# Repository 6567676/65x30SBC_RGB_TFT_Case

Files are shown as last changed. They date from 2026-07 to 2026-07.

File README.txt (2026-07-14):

项目简介

适配30×65mm sbc的rgb+副屏海景房机箱
android设备通过app与ble蓝牙控制灯效与副屏
7颗ws2812支持三种灯效，通过android设备外录与内录实现频谱拾音灯
st7789 1.47寸 320×172副屏支持显示图片与播放视频
视频最高70s 21fps@rgb565，插帧后可达42fps
机箱两侧设有风扇主动散热

技术实现

基于esp32 s3 n16r8  st7789  ws2812  rtos  android15
双核四缓冲流水线，块匹配运动补偿+加权混色插帧，dma行扫描刷新，flash增量擦除顺序写入
gamma曲线呼吸，脉冲灯效，频谱灯低通滤波，自定义gamma lut(解决ws2812高亮度变化小问题)
nim ble零配对mtu 247，三通道分离指令/数据/回执，状态机分流，视频帧异步落flash，ack回执流控
外录+内录双音源切换，实时FFT频谱分析，7频段dBFS归一化+自动对比度拉伸
MediaCodec解码+自定义裁剪区域，逐帧JPEG压缩，本地存储预览+异步上传

开源协议

CC BY-NC 4.0
Copyright (c) 2026 6567676
You are free to:
  - Share and redistribute in any medium or format
  - Remix, transform, and build upon the material
Under the following terms:
  - NonCommercial only
Full license: https://creativecommons.org/licenses/by-nc/4.0/

其他

此项目仅在瑞莎zero 3w，hyperOS 3完成验证

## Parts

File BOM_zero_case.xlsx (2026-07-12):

No. | Quantity | Comment | Footprint | Manufacturer Part | Manufacturer
1 | 6 | 100nF | C0603 | 0603B104K500NT | FH(风华)
2 | 2 | 1uF | C0805 | 0805B105K500NT | FH(风华)
3 | 1 | FC-05A8P11H20 | FPC-SMD_8P-P0.50_FC05-S08FCT-00 | FC-05A8P11H20 | BXCONN(宝讯)
4 | 7 | WS2812B-V5/W | LED-SMD_4P-L5.0-W5.0-TL-1 | WS2812B-V5/W | worldsemi
5 | 1 | AMS1117-3.3V | SOT-89-3_L4.5-W2.5-P1.50-LS4.2-BR | AMS1117-3.3V | MSKSEMI(美森科)
6 | 1 | 10kΩ | R0603 | FRC0603J472 TS | FOJAN(富捷)
7 | 2 | 5.1kΩ | R0603 | FRC0603J472 TS | FOJAN(富捷)
8 | 1 | 10Ω | R0603 | FRC0603J472 TS | FOJAN(富捷)
9 | 1 | TS-1088-AR02016 | SW-SMD_L3.9-W3.0-P4.45 | TS-1088-AR02016 | XUNPU(讯普)
10 | 1 | 2.4GHz | WIRELM-SMD_ESP32-S3-WROOM-1 | ESP32-S3-WROOM-1-N16R8 | ESPRESSIF(乐鑫)
11 | 1 | TYPE-C 16PIN 2MD(073) | USB-C-SMD_TYPE-C-16PIN-2MD-073 | TYPE-C 16PIN 2MD(073) | SHOU HAN(首韩)
12 | 2 | 1.15cfm | 2510 | 散热风扇
13 | 6 |  | M3*2.5 | 热熔螺母
14 | 4 |  | M3*4 | 尼龙螺丝
15 | 2 |  | M3*6 | 尼龙螺丝
16 | 4 |  | M2.5*8 | 尼龙螺丝
17 | 4 |  | M2.5*14 | 尼龙螺丝
18 | 4 |  | M2.5 | 尼龙螺母
19 | 4 |  | 4*2.7*2 | 隔离柱
20 | 1 | 320*172 262k | 1.47寸 插接8p | ST7789 TFT彩屏
21 | 1 | 84*27*1mm |  | 亚克力板
22 | 1 | 84*28*1mm |  | 亚克力板
23 |  |  |  | 硅橡胶 焊锡

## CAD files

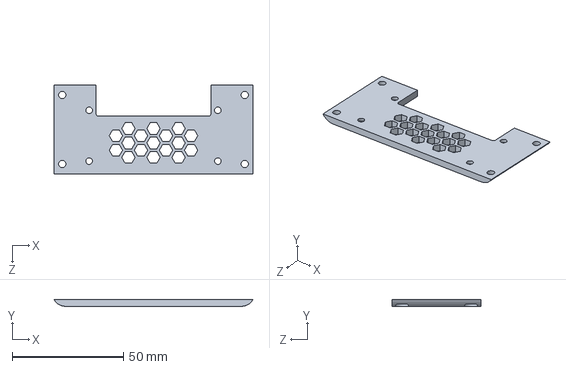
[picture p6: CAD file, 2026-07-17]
zero_case_part/底板.SLDPRT
89.4 x 3.00 x 40.0 mm

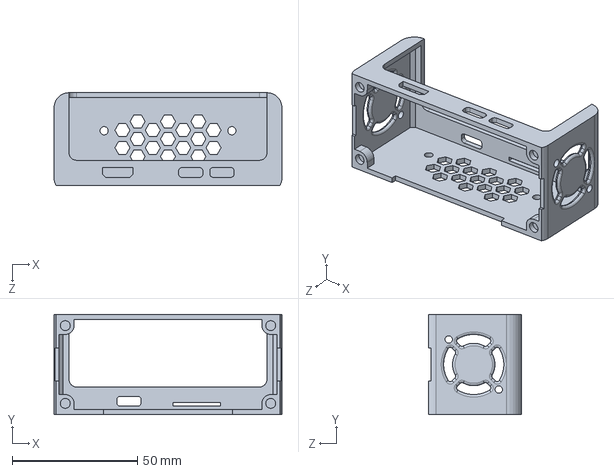
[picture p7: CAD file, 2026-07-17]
zero_case_part/主体.SLDPRT
91.0 x 40.0 x 37.0 mm

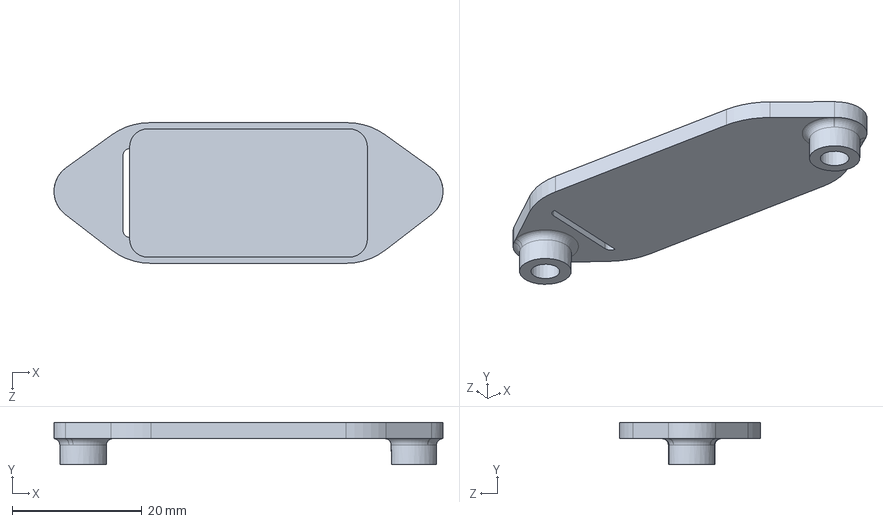
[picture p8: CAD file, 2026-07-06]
zero_case_part/屏幕支架.SLDPRT
60.0 x 6.50 x 21.7 mm

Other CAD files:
zero_case_part/主体.STL
zero_case_part/屏幕支架.STL
zero_case_part/底板.STL

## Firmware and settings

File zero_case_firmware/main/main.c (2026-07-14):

#include <string.h>
#include <stdio.h>
#include <math.h>
#include "freertos/FreeRTOS.h"
#include "freertos/task.h"
#include "freertos/semphr.h"
#include "esp_log.h"
#include "esp_timer.h"
#include "nvs_flash.h"
#include "nvs.h"
#include "driver/spi_master.h"
#include "driver/gpio.h"
#include "esp_flash.h"
#include "esp_heap_caps.h"

#include "nimble/nimble_port.h"
#include "nimble/nimble_port_freertos.h"
#include "host/ble_hs.h"
#include "host/ble_gatt.h"
#include "services/gap/ble_svc_gap.h"
#include "services/gatt/ble_svc_gatt.h"

#include "led_strip.h"
#include "jpeg_decoder.h"

static const char *TAG = "ZERO_BOX";

// ==================== BLE ====================
#define BLE_DEVICE_NAME    "zero box"
#define ZEROBOX_SVC_UUID   0xFF01
#define ZEROBOX_CMD_UUID   0xFF02
#define ZEROBOX_DATA_UUID  0xFF03
#define ZEROBOX_ACK_UUID   0xFF04

// ==================== 硬件 ====================
#define WS2812_GPIO_NUM    38
#define LED_NUM            7
#define LED_MODE_ON        1
#define LED_MODE_BREATH    2
#define LED_MODE_PULSE     3
#define LED_MODE_AUDIO     4

#define IMAGE_W           320
#define IMAGE_H           172
#define IMAGE_SIZE        (IMAGE_W * IMAGE_H * 2)

#define LCD_HOST          SPI2_HOST
#define LCD_SCL           17
#define LCD_SDA           16
#define LCD_CS            18
#define LCD_DC            15
#define LCD_RES           7


// ==================== Flash 存储 ====================
#define MEDIA_FLASH_ADDR    0x320000
#define MEDIA_FLASH_SIZE    (14 * 1024 * 1024)
#define MEDIA_SECTOR_SIZE   8192
#define MEDIA_DATA_START    (MEDIA_FLASH_ADDR + MEDIA_SECTOR_SIZE)

#define IMAGE_MAGIC         0x494D4700
#define VIDEO_MAGIC         0x56494445
#define MAX_VIDEO_FRAMES    1422
#include "freertos/queue.h"
static const uint8_t audio_lut[] = {
     3,  4,  5,  6,  7,  8,  9, 10, 11, 12, 13, 14, 15, 16, 17, 18,
    19, 20, 21, 22, 23, 24, 25, 26, 27, 28, 29, 30, 31, 32, 33, 34,
    35, 36, 37, 38, 39, 40, 41, 42, 43, 44, 45, 46, 47, 48, 49, 50,
    51, 53, 55, 58, 61, 65, 69, 74, 79, 85, 91, 98,105,113,121,130,
   139,148,158,168,178,189,200,211,222,233,244,255
};

// ==================== JPEG 缓冲 ====================
#define JPEG_BUF_SIZE      (96 * 1024)
typedef struct {
    uint8_t *data;
    uint32_t len;
} flash_write_item_t;
static QueueHandle_t flash_queue = NULL;

static uint8_t  jpeg_buf[JPEG_BUF_SIZE] __attribute__((aligned(4)));
static int      jpeg_offset = 0;
static int      jpeg_expected = 0;
static bool     jpeg_receiving = false;

static uint8_t  g_image_data[IMAGE_SIZE] __attribute__((aligned(4)));
static bool     g_image_valid = false;

static uint16_t audio_bands[7] = {0};
static uint8_t  audio_level = 0;
static bool     audio_active = false;
static uint8_t *vbuf[4] = {NULL, NULL, NULL, NULL};

// ==================== LED ====================
static uint8_t led_current_mode = LED_MODE_ON;
static uint8_t prev_mode = 0;
static uint8_t target_r = 255, target_g = 255, target_b = 255;
static uint8_t global_brightness = 255;

static led_strip_handle_t  led_strip;
static spi_device_handle_t  lcd_spi;

// ==================== BLE 状态 ====================
static uint16_t ble_conn_handle = BLE_HS_CONN_HANDLE_NONE;
static uint8_t  ble_addr_type;
static int      ble_img_offset = 0;
static bool     ble_img_receiving = false;
static SemaphoreHandle_t img_save_sem = NULL;
static SemaphoreHandle_t jpeg_decode_sem = NULL;

static uint16_t ack_chr_val_handle = 0;
static bool     ack_subscribed = false;

// ==================== 视频接收状态 ====================
static bool     video_receiving = false;
static int      video_state = 0;
static int      video_total_frames = 0;
static int      video_current_frame = 0;
static int      video_frame_size = 0;
static int      video_frame_offset = 0;
static uint32_t video_frame_sizes[MAX_VIDEO_FRAMES];
static int      video_queued_frames = 0;
static uint32_t video_flash_addr = 0;
static uint32_t video_next_erase = 0;

// ==================== 视频播放状态（从 Flash 加载）====================
static volatile bool     has_stored_video = false;
static int      stored_video_frames = 0;
static uint32_t stored_frame_sizes[MAX_VIDEO_FRAMES];
static uint32_t stored_frame_offsets[MAX_VIDEO_FRAMES];

// 播放控制
static volatile bool     playback_active = false;
static volatile int video_progress_percent = -1;
static bool screen_cleared = false;

// 双核播放
static QueueHandle_t display_queue = NULL;
static QueueHandle_t buf_free_queue = NULL;

#define NVS_CFG_NAMESPACE  "led_cfg"

// ==================== 亮度计算 ====================
static inline uint8_t calc_brightness(uint8_t phase) {
    uint32_t x = (phase < 128) ? phase : (256 - phase);
    return (uint8_t)(5 + (250 * x * (256 - x)) / 16384);
}

// ==================== JPEG 解码 ====================
static esp_err_t decode_jpeg_to_rgb565(const uint8_t *jpg, int jpg_len,
                                        uint8_t *out, int out_size) {
    esp_jpeg_image_cfg_t cfg = {
        .indata = (uint8_t *)jpg,
        .indata_size = jpg_len,
        .outbuf = out,
        .outbuf_size = out_size,
        .out_format = JPEG_IMAGE_FORMAT_RGB565,
        .out_scale = JPEG_IMAGE_SCALE_0,
        .flags = { .swap_color_bytes = 1 },
    };
    esp_jpeg_image_output_t img;
    return esp_jpeg_decode(&cfg, &img);
}

// ==================== BLE ACK 发送 ====================
static void send_ack(uint8_t ack_code) {
    if (!ack_subscribed || ble_conn_handle == BLE_HS_CONN_HANDLE_NONE) return;
    struct os_mbuf *om = ble_hs_mbuf_from_flat(&ack_code, 1);
    if (om) {
        ble_gattc_notify_custom(ble_conn_handle, ack_chr_val_handle, om);
    }
}

static void save_image_to_flash(const uint8_t *data, size_t len) {
    if (len != IMAGE_SIZE) return;
    playback_active = false;
    has_stored_video = false;
    size_t erase_size = MEDIA_SECTOR_SIZE + len;
    erase_size = (erase_size + MEDIA_SECTOR_SIZE - 1) & ~(MEDIA_SECTOR_SIZE - 1);
    esp_flash_erase_region(NULL, MEDIA_FLASH_ADDR, erase_size);
    uint32_t header[2] = { IMAGE_MAGIC, IMAGE_SIZE };
    esp_flash_write(NULL, header, MEDIA_FLASH_ADDR, sizeof(header));
    esp_flash_write(NULL, data, MEDIA_DATA_START, len);
    memcpy(g_image_data, data, len);
    g_image_valid = true;
}

static void load_image_from_flash(void) {
    uint32_t header[2];
    esp_flash_read(NULL, header, MEDIA_FLASH_ADDR, sizeof(header));
    if (header[0] != IMAGE_MAGIC) return;
    if (header[1] != IMAGE_SIZE) return;
    esp_flash_read(NULL, g_image_data, MEDIA_DATA_START, IMAGE_SIZE);
    g_image_valid = true;
}

// ==================== Flash: 视频存取 ====================
static void finalize_video_save(int frame_count) {
	video_progress_percent = -1;
	screen_cleared = false;
    uint32_t header[4];
    header[0] = VIDEO_MAGIC;
    header[1] = (uint32_t)frame_count;
    header[2] = 0;
    header[3] = 0;

    esp_flash_write(NULL, header, MEDIA_FLASH_ADDR, sizeof(header));
    esp_flash_write(NULL, video_frame_sizes,
                     MEDIA_FLASH_ADDR + sizeof(header),
                     frame_count * 4);

    has_stored_video = true;
    stored_video_frames = frame_count;
    memcpy(stored_frame_sizes, video_frame_sizes, frame_count * 4);

    stored_frame_offsets[0] = 0;
    for (int i = 1; i < frame_count; i++) {
        stored_frame_offsets[i] = stored_frame_offsets[i - 1] + stored_frame_sizes[i - 1];
    }
    ESP_LOGI(TAG, "Video saved: %d frames", frame_count);
}

static void load_video_from_flash(void) {
    uint32_t header[4];
    esp_flash_read(NULL, header, MEDIA_FLASH_ADDR, sizeof(header));
    if (header[0] != VIDEO_MAGIC) return;
    stored_video_frames = (int)header[1];
    if (stored_video_frames <= 0 || stored_video_frames > MAX_VIDEO_FRAMES) return;

    esp_flash_read(NULL, stored_frame_sizes,
                     MEDIA_FLASH_ADDR + sizeof(header),
                     stored_video_frames * 4);

    stored_frame_offsets[0] = 0;
    for (int i = 1; i < stored_video_frames; i++) {
        stored_frame_offsets[i] = stored_frame_offsets[i - 1] + stored_frame_sizes[i - 1];
    }
    has_stored_video = true;
}

static void load_media_from_flash(void) {
    uint32_t magic;
    esp_flash_read(NULL, &magic, MEDIA_FLASH_ADDR, 4);
    if (magic == VIDEO_MAGIC) load_video_from_flash();
    else if (magic == IMAGE_MAGIC) load_image_from_flash();
}

// ==================== LCD ====================
static void lcd_cmd(uint8_t cmd) {
    gpio_set_level(LCD_DC, 0);
    spi_transaction_t t = {.length = 8, .tx_buffer = &cmd};
    spi_device_transmit(lcd_spi, &t);
}

static void lcd_data(uint8_t data) {
    gpio_set_level(LCD_DC, 1);
    spi_transaction_t t = {.length = 8, .tx_buffer = &data};
    spi_device_transmit(lcd_spi, &t);
}

static void lcd_set_window(uint16_t x1, uint16_t y1, uint16_t x2, uint16_t y2) {
    y1 += 34; y2 += 34;
    lcd_cmd(0x2A);
    lcd_data(x1 >> 8); lcd_data(x1);
    lcd_data(x2 >> 8); lcd_data(x2);
    lcd_cmd(0x2B);
    lcd_data(y1 >> 8); lcd_data(y1);
    lcd_data(y2 >> 8); lcd_data(y2);
    lcd_cmd(0x2C);
}

void lcd_init(void) {
    gpio_set_direction(LCD_RES, GPIO_MODE_OUTPUT);
    gpio_set_direction(LCD_DC, GPIO_MODE_OUTPUT);
    gpio_set_level(LCD_RES, 0); vTaskDelay(20);
    gpio_set_level(LCD_RES, 1); vTaskDelay(120);

        spi_bus_config_t bus_cfg = {
        .mosi_io_num = LCD_SDA,
        .sclk_io_num = LCD_SCL,
        .miso_io_num = -1,
        
    };
    spi_bus_initialize(LCD_HOST, &bus_cfg, SPI_DMA_CH_AUTO);

    spi_device_interface_config_t dev_cfg = {
        .clock_speed_hz = 80 * 1000 * 1000,
        .mode = 0,
        .spics_io_num = LCD_CS,
        .queue_size = 1,
    };
    spi_bus_add_device(LCD_HOST, &dev_cfg, &lcd_spi);

    lcd_cmd(0x11); vTaskDelay(120);
    lcd_cmd(0x36); lcd_data(0xa0);
    lcd_cmd(0x3A); lcd_data(0x55);
    lcd_cmd(0x21);
    lcd_cmd(0x29);
}

void lcd_show_image(const uint16_t *img) {
    static uint16_t line_buf[IMAGE_W] __attribute__((aligned(4)));
    lcd_set_window(0, 0, IMAGE_W - 1, IMAGE_H - 1);
    gpio_set_level(LCD_DC, 1);
    spi_transaction_t t = { .length = IMAGE_W * 16, .tx_buffer = line_buf };
    for (int y = 0; y < IMAGE_H; y++) {
        memcpy(line_buf, img + y * IMAGE_W, IMAGE_W * 2);
        spi_device_transmit(lcd_spi, &t);
    }
}

void lcd_show_image_fast(const uint16_t *img) {
    lcd_set_window(0, 0, IMAGE_W - 1, IMAGE_H - 1);
    gpio_set_level(LCD_DC, 1);
    for (int y = 0; y < IMAGE_H; y += 4) {
        int n = (y + 4 <= IMAGE_H) ? 4 : (IMAGE_H - y);
        spi_transaction_t t = {
            .length = IMAGE_W * n * 16,
            .tx_buffer = img + y * IMAGE_W,
        };
        spi_device_polling_transmit(lcd_spi, &t);
    }
}

static void find_motion(const uint16_t *prev, const uint16_t *curr,
                         int *out_dx, int *out_dy) {
    int best_sad = 0x7FFFFFFF;
    *out_dx = 0;
    *out_dy = 0;
        for (int dy = -3; dy <= 3; dy++) {
        for (int dx = -3; dx <= 3; dx++) {
            int sad = 0;
            for (int y = 10; y < IMAGE_H; y += 60) {
                int sy = y + dy;
                if (sy < 0 || sy >= IMAGE_H) continue;
                for (int x = 20; x < IMAGE_W; x += 60) {
                    int sx = x + dx;
                    if (sx < 0 || sx >= IMAGE_W) continue;
                    uint16_t a = prev[sy * IMAGE_W + sx];
                    uint16_t b = curr[y * IMAGE_W + x];
                    sad += abs((int)(a & 0xFF) - (int)(b & 0xFF)) +
                           abs((int)(a >> 8) - (int)(b >> 8));
                }
            }
            if (sad < best_sad) {
                best_sad = sad;
                *out_dx = dx;
                *out_dy = dy;
            }
        }
    }
}

void lcd_show_image_blend(const uint16_t *img_a, const uint16_t *img_b,
                           int mdx, int mdy) {
    static uint16_t line_buf[IMAGE_W * 4] __attribute__((aligned(4)));
    lcd_set_window(0, 0, IMAGE_W - 1, IMAGE_H - 1);
    gpio_set_level(LCD_DC, 1);

    if (mdx == 0 && mdy == 0) {
        for (int y = 0; y < IMAGE_H; y += 4) {
            int n = (y + 4 <= IMAGE_H) ? 4 : (IMAGE_H - y);
            for (int line = 0; line < n; line++) {
                const uint16_t *pa = img_a + (y + line) * IMAGE_W;
                const uint16_t *pb = img_b + (y + line) * IMAGE_W;
                uint16_t *dst = line_buf + line * IMAGE_W;
                for (int x = 0; x < IMAGE_W; x++) {
                    uint16_t a = (pa[x] >> 8) | (pa[x] << 8);
                    uint16_t b = (pb[x] >> 8) | (pb[x] << 8);
                    uint32_t r  = (((a >> 11) & 0x1F) + ((b >> 11) & 0x1F) * 3) >> 2;
                    uint32_t g  = (((a >> 5)  & 0x3F) + ((b >> 5)  & 0x3F) * 3) >> 2;
                    uint32_t bl = (( a        & 0x1F) + ( b        & 0x1F) * 3) >> 2;
                    uint16_t out = (uint16_t)((r << 11) | (g << 5) | bl);
                    dst[x] = (out >> 8) | (out << 8);
                }
            }
            spi_transaction_t t = { .length = IMAGE_W * n * 16, .tx_buffer = line_buf };
            spi_device_polling_transmit(lcd_spi, &t);
        }
        return;
    }

    int ol_start = (mdx > 0) ? mdx : 0;
    int ol_end   = (mdx < 0) ? (IMAGE_W + mdx) : IMAGE_W;

    for (int y = 0; y < IMAGE_H; y += 4) {
        int n = (y + 4 <= IMAGE_H) ? 4 : (IMAGE_H - y);
        for (int line = 0; line < n; line++) {
            int row = y + line;
            int ay = row - mdy;
            uint16_t *dst = line_buf + line * IMAGE_W;
            if (ay < 0 || ay >= IMAGE_H) {
                memcpy(dst, img_b + row * IMAGE_W, IMAGE_W * 2);
            } else {
                const uint16_t *ra = img_a + ay * IMAGE_W;
                const uint16_t *rb = img_b + row * IMAGE_W;
                for (int x = 0; x < ol_start; x++)
                    dst[x] = rb[x];
                for (int x = ol_start; x < ol_end; x++) {
                    uint16_t av = (ra[x - mdx] >> 8) | (ra[x - mdx] << 8);
                    uint16_t bv = (rb[x] >> 8) | (rb[x] << 8);
                    uint32_t r  = (((av >> 11) & 0x1F) + ((bv >> 11) & 0x1F) * 3) >> 2;
                    uint32_t g  = (((av >> 5)  & 0x3F) + ((bv >> 5)  & 0x3F) * 3) >> 2;
                    uint32_t bl = (( av        & 0x1F) + ( bv        & 0x1F) * 3) >> 2;
                    uint16_t out = (uint16_t)((r << 11) | (g << 5) | bl);
                    dst[x] = (out >> 8) | (out << 8);
                }
                for (int x = ol_end; x < IMAGE_W; x++)
                    dst[x] = rb[x];
            }
        }
        spi_transaction_t t = { .length = IMAGE_W * n * 16, .tx_buffer = line_buf };
        spi_device_polling_transmit(lcd_spi, &t);
    }
}

// ==================== Video Progress ====================
#define PROG_Y1     65
#define PROG_Y2     103
#define BAR_X1      30
#define BAR_X2      290
#define BAR_Y1      91
#define BAR_Y2      103

static const uint8_t prog_font[][8] = {
    {0x3C,0x42,0x42,0x42,0x42,0x42,0x3C,0x00}, // 0
    {0x10,0x30,0x50,0x10,0x10,0x10,0x7C,0x00}, // 1
    {0x3C,0x42,0x02,0x0C,0x30,0x40,0x7E,0x00}, // 2
    {0x3C,0x42,0x02,0x1C,0x02,0x42,0x3C,0x00}, // 3
    {0x08,0x18,0x28,0x48,0x7C,0x08,0x08,0x00}, // 4
    {0x7E,0x40,0x7C,0x02,0x02,0x42,0x3C,0x00}, // 5
    {0x1C,0x20,0x40,0x7C,0x42,0x42,0x3C,0x00}, // 6
    {0x7E,0x42,0x04,0x08,0x10,0x10,0x10,0x00}, // 7
    {0x3C,0x42,0x42,0x3C,0x42,0x42,0x3C,0x00}, // 8
    {0x3C,0x42,0x42,0x3E,0x02,0x04,0x38,0x00}, // 9
    {0x00,0x44,0x28,0x10,0x28,0x44,0x00,0x00}, // %
};

static int64_t last_prog_us = 0;


static void show_video_progress(int percent) {
    static uint16_t line[IMAGE_W];

    int64_t now = esp_timer_get_time();
    if (now - last_prog_us < 33333) return;
    last_prog_us = now;

    if (percent < 0) percent = 0;
    if (percent > 100) percent = 100;

    if (!screen_cleared) {
        memset(line, 0, IMAGE_W * 2);
        lcd_set_window(0, 0, IMAGE_W - 1, IMAGE_H - 1);
        gpio_set_level(LCD_DC, 1);
        for (int y = 0; y < IMAGE_H; y++) {
            spi_transaction_t t = { .length = IMAGE_W * 16, .tx_buffer = line };
            spi_device_polling_transmit(lcd_spi, &t);
        }
        screen_cleared = true;
    }

    char text[5];
    int tlen;
    if (percent >= 100)     { text[0]='1'; text[1]='0'; text[2]='0'; text[3]='%'; tlen=4; }
    else if (percent >= 10) { text[0]='0'+percent/10; text[1]='0'+percent%10; text[2]='%'; tlen=3; }
    else                    { text[0]='0'+percent; text[1]='%'; tlen=2; }

    int text_x0 = (IMAGE_W - tlen * 16) / 2;
    int text_y0 = 65;

    lcd_set_window(0, PROG_Y1, IMAGE_W - 1, PROG_Y2);
    gpio_set_level(LCD_DC, 1);

    for (int y = PROG_Y1; y <= PROG_Y2; y++) {
        memset(line, 0, IMAGE_W * 2);

        int fy = (y - text_y0) >> 1;
        if (fy >= 0 && fy < 8) {
            for (int ci = 0; ci < tlen; ci++) {
                int idx = (text[ci] == '%') ? 10 : (text[ci] - '0');
                if (idx < 0 || idx > 10) continue;
                uint8_t bits = prog_font[idx][fy];
                int cx = text_x0 + ci * 16;
                for (int fx = 0; fx < 8; fx++) {
                    if (bits & (0x80 >> fx)) {
                        int px = cx + fx * 2;
                        if (px >= 0 && px + 1 < IMAGE_W) {
                            line[px] = 0xFFFF;
                            line[px + 1] = 0xFFFF;
                        }
                    }
                }
            }
        }

        if (y >= BAR_Y1 && y <= BAR_Y2) {
            if (y == BAR_Y1 || y == BAR_Y2) {
                for (int x = BAR_X1; x <= BAR_X2; x++)
                    line[x] = 0xFFFF;
            } else {
                line[BAR_X1] = 0xFFFF;
                line[BAR_X2] = 0xFFFF;
                int fill = (BAR_X2 - BAR_X1 - 1) * percent / 100;
                for (int x = 1; x <= fill; x++)
                    line[BAR_X1 + x] = 0xFFFF;
            }
        }

        spi_transaction_t t = { .length = IMAGE_W * 16, .tx_buffer = line };
        spi_device_polling_transmit(lcd_spi, &t);
    }
}

// ==================== NVS ====================
void save_config(void) {
    nvs_handle_t h;
    if (nvs_open(NVS_CFG_NAMESPACE, NVS_READWRITE, &h) == ESP_OK) {
        nvs_set_u8(h, "mode", led_current_mode);
        nvs_set_u8(h, "r", target_r);
        nvs_set_u8(h, "g", target_g);
        nvs_set_u8(h, "b", target_b);
        nvs_set_u8(h, "bright", global_brightness);
        nvs_commit(h);
        nvs_close(h);
    }
}

void load_config(void) {
    nvs_handle_t h;
    if (nvs_open(NVS_CFG_NAMESPACE, NVS_READONLY, &h) == ESP_OK) {
        nvs_get_u8(h, "mode", &led_current_mode);
        nvs_get_u8(h, "r", &target_r);
        nvs_get_u8(h, "g", &target_g);
        nvs_get_u8(h, "b", &target_b);
        nvs_get_u8(h, "bright", &global_brightness);
        nvs_close(h);
    }
}

// ==================== BLE GAP ====================
static void start_advertising(void);
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
void app_main(void) {
	esp_log_level_set("spi_master", ESP_LOG_NONE);  // 最前面
    esp_err_t ret = nvs_flash_init();
    if (ret == ESP_ERR_NVS_NO_FREE_PAGES || ret == ESP_ERR_NVS_NEW_VERSION_FOUND) {
        nvs_flash_erase();
        nvs_flash_init();
    }

    ESP_LOGI(TAG, "ZERO_BOX START");

    lcd_init();
    esp_log_level_set("spi_master", ESP_LOG_WARN);
    load_media_from_flash();
    load_config();

    if (g_image_valid && !has_stored_video) {
        lcd_show_image((uint16_t *)g_image_data);
    }

    if (has_stored_video) {
        playback_active = true;
    }
    
    nimble_port_init();
    ble_hs_cfg.sm_io_cap = BLE_HS_IO_NO_INPUT_OUTPUT;
    ble_hs_cfg.sm_bonding = 0;
    ble_hs_cfg.sm_mitm = 0;
    ble_hs_cfg.sm_sc = 0;
    ble_hs_cfg.sm_our_key_dist = 0;
    ble_hs_cfg.sm_their_key_dist = 0;
    ble_hs_cfg.reset_cb = ble_on_reset;
    ble_hs_cfg.sync_cb = ble_on_sync;

    ble_svc_gap_init();
    ble_svc_gatt_init();
    ble_gatts_count_cfg(gatt_svcs);
    ble_gatts_add_svcs(gatt_svcs);
    ble_svc_gap_device_name_set(BLE_DEVICE_NAME);
    
    img_save_sem = xSemaphoreCreateBinary();
    jpeg_decode_sem = xSemaphoreCreateBinary();
    flash_queue = xQueueCreate(16, sizeof(flash_write_item_t));
    xTaskCreatePinnedToCore(flash_write_task, "flash_wr", 4096, NULL, 3, NULL, 1);
    xTaskCreatePinnedToCore(img_save_task, "img_save", 8192, NULL, 3, NULL, 1);

    vbuf[0] = heap_caps_malloc(IMAGE_SIZE, MALLOC_CAP_SPIRAM);
    vbuf[1] = heap_caps_malloc(IMAGE_SIZE, MALLOC_CAP_SPIRAM);
    vbuf[2] = heap_caps_malloc(IMAGE_SIZE, MALLOC_CAP_SPIRAM);
    vbuf[3] = heap_caps_malloc(IMAGE_SIZE, MALLOC_CAP_SPIRAM);
    if (vbuf[0] && vbuf[1] && vbuf[2] && vbuf[3]) {
        display_queue = xQueueCreate(4, sizeof(int));
        buf_free_queue = xQueueCreate(4, sizeof(int));
        for (int i = 0; i < 4; i++) xQueueSend(buf_free_queue, &i, 0);
        xTaskCreatePinnedToCore(video_decode_task, "vid_dec", 4096, NULL, 5, NULL, 0);
        xTaskCreatePinnedToCore(video_display_task, "vid_disp", 4096, NULL, 4, NULL, 1);
    }
    xTaskCreatePinnedToCore(led_task, "led_task", 4096, NULL, 3, NULL, 1);
    nimble_port_freertos_init(ble_host_task);
}

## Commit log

2026-07-05 auto sync 2026-07-05 15:56:20
    [底板.SLDPRT]
2026-07-05 auto sync 2026-07-05 15:56:38
    [底板.SLDPRT]
2026-07-05 auto sync 2026-07-05 15:56:56
    [底板.SLDPRT]
2026-07-05 auto sync 2026-07-05 15:57:21
    [底板.SLDPRT]
2026-07-05 auto sync 2026-07-05 15:57:38
    [底板.SLDPRT]
2026-07-05 auto sync 2026-07-05 15:58:10
    [底板.SLDPRT]
2026-07-06 auto sync 2026-07-06 14:15:49
    [底板.SLDPRT, 底板.STL]
2026-07-06 auto sync 2026-07-06 14:35:58
    [底板.SLDPRT]
2026-07-06 auto sync 2026-07-06 16:33:07
    [BOM_zero_case.xlsx]
2026-07-06 auto sync 2026-07-06 16:54:03
    [主体.SLDPRT]
2026-07-06 auto sync 2026-07-06 17:15:36
    [底板.SLDPRT]
2026-07-06 auto sync 2026-07-06 17:16:08
    [底板.SLDPRT]
2026-07-06 auto sync 2026-07-06 17:17:07
    [底板.SLDPRT]
2026-07-06 auto sync 2026-07-06 17:17:43
    [底板1.SLDPRT]
2026-07-06 auto sync 2026-07-06 17:17:54
    [底板1.SLDPRT]
2026-07-06 auto sync 2026-07-06 17:22:48
    [主体.SLDPRT, 底板.SLDPRT]
2026-07-06 auto sync 2026-07-06 17:27:31
    [底板.SLDPRT]
2026-07-06 auto sync 2026-07-06 17:27:45
    [底板.STL]
2026-07-06 auto sync 2026-07-06 17:29:44
    [屏幕支架.STL]
2026-07-06 auto sync 2026-07-06 20:16:41
    [屏幕支架.SLDPRT]
2026-07-06 auto sync 2026-07-06 20:31:58
    [屏幕支架.SLDPRT]
2026-07-06 auto sync 2026-07-06 20:32:20
    [屏幕支架.STL]
2026-07-07 auto sync 2026-07-07 09:30:02
    [主体.SLDPRT, 底板.SLDPRT]
2026-07-07 auto sync 2026-07-07 09:30:21
    [主体.STL]
2026-07-07 auto sync 2026-07-07 09:30:46
    [主体.SLDPRT]
2026-07-08 auto sync 2026-07-08 11:25:11
    [BOM_zero_case.xlsx, 主体.SLDPRT, 底座.SLDPRT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]
2026-07-08 auto sync 2026-07-08 11:25:31
    [BOM_zero_case.xlsx]
2026-07-12 auto sync 2026-07-12 23:10:43
    [BOM_zero_case.xlsx, 主体.SLDPRT]
2026-07-17 auto sync 2026-07-17 15:37:57
    [主体.SLDPRT, 底板.SLDPRT]
